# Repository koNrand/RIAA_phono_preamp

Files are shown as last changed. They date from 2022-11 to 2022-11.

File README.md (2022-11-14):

# RIAA compatible phono preamp

based on information from an [article](https://hifi.de/feature/technik-erklaert-phono-vorverstaerker-56652) from hifi.de I designed an phono preamp for my turn table.
The project contains an simulation of the equalizing circuit with an amplifier. 
In the KiCad project is 34x72mm PCB with rounded edges so the circuit fits in standard IP54 75x35x40mm cable boxes.
The final stereo circuit comes with with an adjustable amplification from 0dB to 60dB for both channel, and USB-A jack as power input and RCA jack inputs.

The `reichelt_special_components_list.csv` contains the most special component and a link to a public list, so you can order than from reichelt.de or look them up and order them whereever you want.

fair use only, open hardware FTW <3

useful links:
- [KiCad](kicad.org/), a free and open source schematic and PCB layout design software, comes with endless awesome plugins. -> a selfmade basics [Tutorial](https://www.youtube.com/watch?v=UdfuM1iF3_Y&list=PLFoTc99xXplq-vwjNqq9S3VKb1se5qiRt) from my friend [Max](https://github.com/backtail)
- [LTSpice](https://www.analog.com/en/design-center/design-tools-and-calculators/ltspice-simulator.html), a free and powerfull SPICE simulation tool for simulating schematics with a graphical UI -> a selfmade basics [Tutorial]([https://www.youtube.com/watch?v=UdfuM1iF3_Y&list=PLFoTc99xXplq-vwjNqq9S3VKb1se5qiRt](https://www.youtube.com/watch?v=mdhnJGWT1hw&list=PLFoTc99xXplqWKGfDIrEuYwgaC7r6RATd)) from my friend [Max](https://github.com/backtail)
- a opamp [Tutorial](https://www.youtube.com/watch?v=Iz0e1WipaIw&list=PLFoTc99xXplpeMX_rCe2f8oruM441F54b) made by myself to be ready to understand, identify and use most important opamp circuits, comes with an practical example and how to use lab bench power supplies, script included in the video description

all tutorials are in german language

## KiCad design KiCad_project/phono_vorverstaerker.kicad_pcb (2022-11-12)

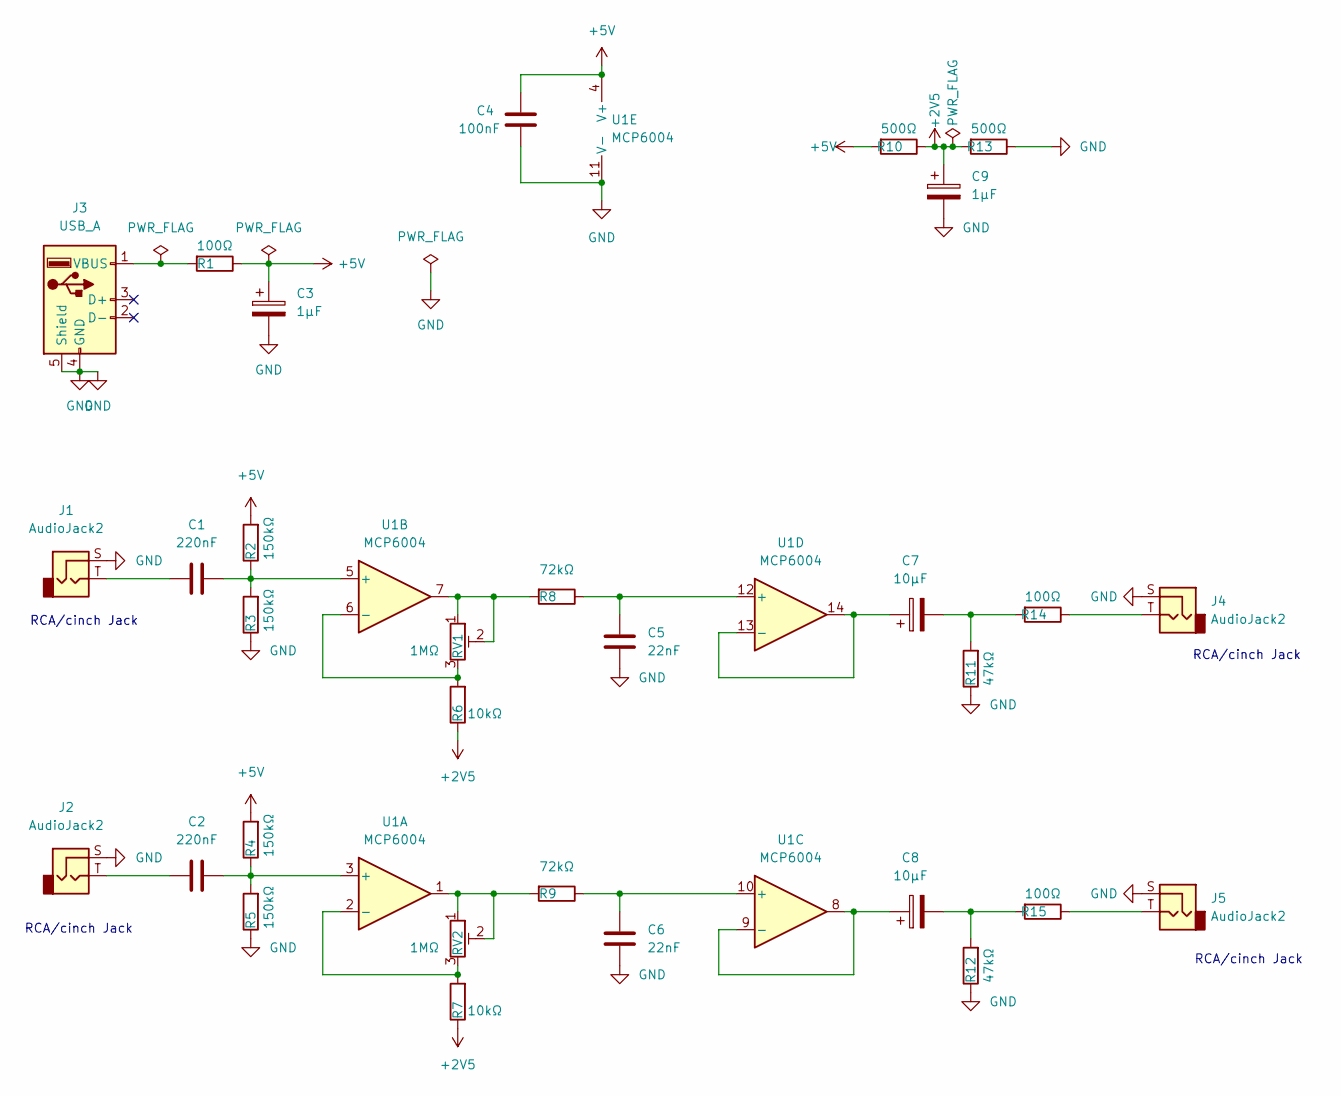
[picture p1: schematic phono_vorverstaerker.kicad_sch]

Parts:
C1, C2: 220nF; C_Disc_D3.4mm_W2.1mm_P2.50mm
C3, C9: 1µF; CP_Radial_D5.0mm_P2.50mm
C4: 100nF; C_Disc_D3.4mm_W2.1mm_P2.50mm
C5, C6: 22nF; C_Disc_D3.4mm_W2.1mm_P2.50mm
C7, C8: 10µF; CP_Radial_D5.0mm_P2.50mm
J1, J2, J4, J5: AudioJack2; cinch_einbaubuchse_CBP_G
J3: USB_A; USB_B_Lumberg_2411_02_Horizontal
R1, R14, R15: 100Ω; R_Axial_DIN0204_L3.6mm_D1.6mm_P7.62mm_Horizontal
R2, R3, R4, R5: 150kΩ; R_Axial_DIN0204_L3.6mm_D1.6mm_P7.62mm_Horizontal
R6, R7: 10kΩ; R_Axial_DIN0204_L3.6mm_D1.6mm_P7.62mm_Horizontal
R8, R9: 72kΩ; R_Axial_DIN0204_L3.6mm_D1.6mm_P7.62mm_Horizontal
R10, R13: 500Ω; R_Axial_DIN0204_L3.6mm_D1.6mm_P7.62mm_Horizontal
R11, R12: 47kΩ; R_Axial_DIN0204_L3.6mm_D1.6mm_P7.62mm_Horizontal
RV1, RV2: 1MΩ; Potentiometer_Bourns_3296W_Vertical
U1: MCP6004; DIP-14_W7.62mm

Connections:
+2V5: C9.1, R6.1, R7.1, R10.1, R13.2
+5V: C3.1, C4.2, R1.1, R2.2, R4.2, R10.2, U1.4 (V+)
GND: C3.2, C4.1, C5.1, C6.1, C9.2, J1.S, J2.S, J3.4 (GND), J3.5 (Shield), J4.S, J5.S, R3.1, R5.1, R11.1, R12.1, R13.1, U1.11 (V-)
unnamed: C1.1, J1.T
unnamed: C2.1, J2.T
unnamed: C7.2, R11.2, R14.2
unnamed: C8.2, R12.2, R15.2
unnamed: J3.1 (VBUS), R1.2
unnamed: J4.T, R14.1
unnamed: J5.T, R15.1
unnamed: R9.2, RV2.1, RV2.2, U1.1
unnamed: R7.2, RV2.3, U1.2 (-)
unnamed: C2.2, R4.1, R5.2, U1.3 (+)
unnamed: C1.2, R2.1, R3.2, U1.5 (+)
unnamed: R6.2, RV1.3, U1.6 (-)
unnamed: R8.2, RV1.1, RV1.2, U1.7
unnamed: C8.1, U1.8, U1.9 (-)
unnamed: C6.2, R9.1, U1.10 (+)
unnamed: C5.2, R8.1, U1.12 (+)
unnamed: C7.1, U1.13 (-), U1.14

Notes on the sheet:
RCA/cinch Jack

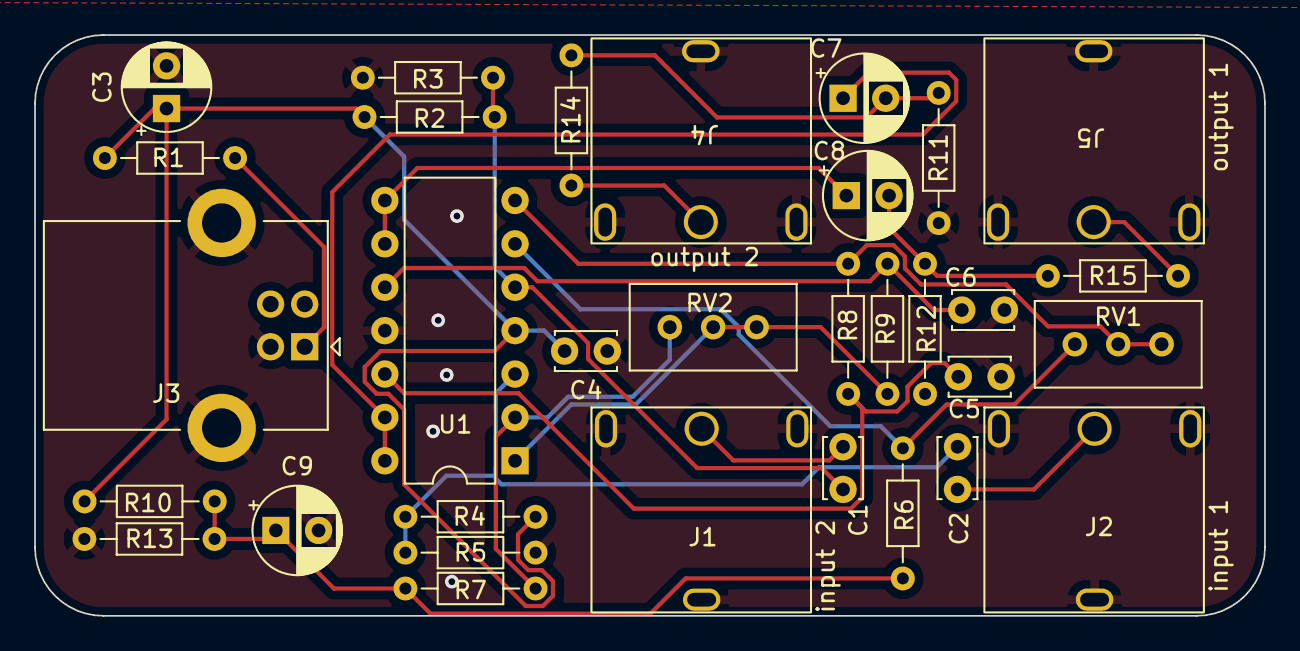
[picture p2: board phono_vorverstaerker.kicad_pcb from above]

Board: 2 copper layers, 72.0 x 34.0 mm, 32 parts (0 on the bottom side), 20 nets.
